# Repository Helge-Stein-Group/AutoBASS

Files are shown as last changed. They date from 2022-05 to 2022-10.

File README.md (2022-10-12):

# :battery: + :robot: + :factory: = AutoBASS 
AutoBASS deploys Automated Battery Assembly System. The motivation of this project is to meet the need of scaling-up and accuate assembly of in-house i.e. non-commercially acquired cells in battery reaserach, therefore enables the data-driven studies on optimization of active materials, electrolyte formulations, processing and manufacturing in a reproducible manner for the investigation of new chemistries.

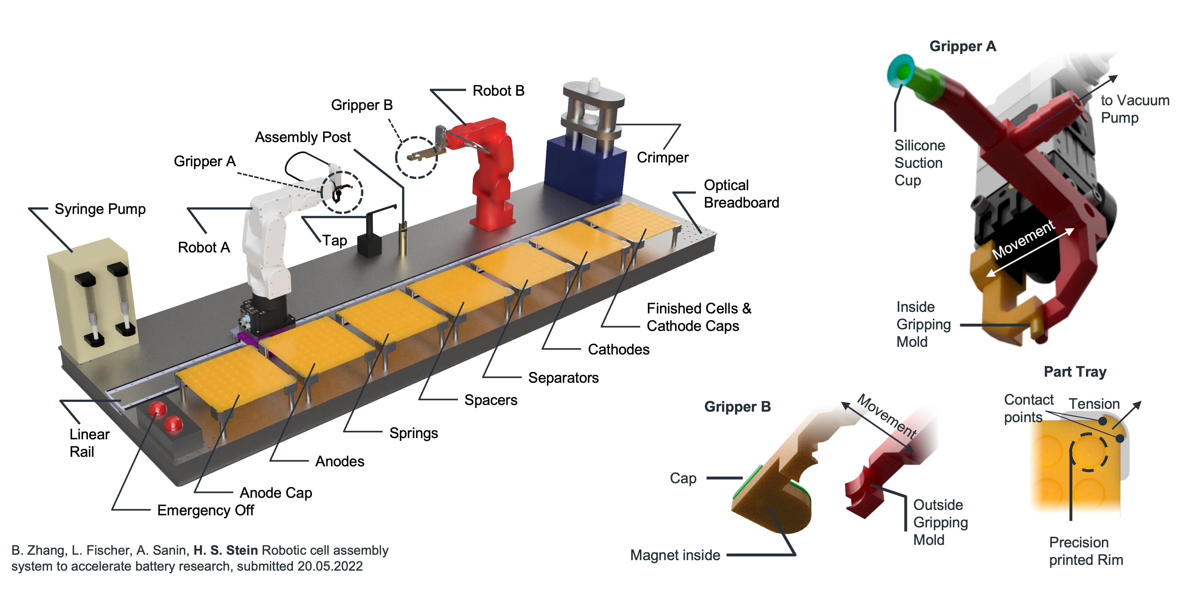
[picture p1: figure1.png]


## What are you here for?

I'm here for:
### Data
Please go to the data folder of this repo. There you will find four zip files which you need to download and unzip:
1. cell_data_published.pck 2.zip.001
2. cell_data_published.pck 2.zip.002
3. cell_data_published.pck 2.zip.003
4. cell_data_published.pck 2.zip.004

The problem is that github only allows binary files of 25 mb size so unzip them somewhere and then you'll get a pickle file that you can read in in python via:

```python
import pickle
data = pickle.load(open(r'/path/to/the/file/cell_data_published.pck','rb'))
```

We did this using python 3.7 so make sure you're not using an outdated version.
Then the data variable will contain all data for all cells (failed or not) as a list of dictionaries.
For each cell we record: 
#### **raw data**
Keys: I, V, t, index, Discharge_Capacity<br/>
Essentially what the arbin spits out. Index is the cycle index. The Discharge_Capacity is this strange Arbin thing which we keep in
#### **semi processed data**
Keys: ocv_assembly, channel, start_time, closing_time, dayli_id, Vsm<br/>
We write down that potential of the first few seconds, which channel was used, when the cycling started, when the cell was closed, some id to track cells internally and a smoothed voltage profile
#### **Cell images**
Keys: anode_image, separator_image, cathode_image<br/>
Relatively self explanatory by name. If there is no image the camera faulted
#### **Derived data**
Keys: dQdV, Q <br/>
This is data we calculate

#### Example Data access:

Ok let's say we want to see the voltage profile of cell 42 the we do this:

```python
import pickle
data = pickle.load(open(r'/path/to/the/file/cell_data_published.pck','rb'))

plt.plot(data[42]['t'],data[42]['V'])
plt.xlabel('Time [s]')
plt.ylabel('Voltage [V]')
```

If you look at the dQ/dV data make sure to scale the plots right as there is still considerable noide in the data. We recooment to plot vs. the smoother Voltage profile which is in the Vsm key.

### Building my own
Have a look at the stl files in the mechanical parts folder.
You will need
1. A Crimper
2. 2x Mecademic Meca 500 r.3
3. 2x Meca compatible Schunk Grippers
4. Jenny Science Linax Linear rail
5. Optical table
6. A 3D printer
7. Possibly our help
8. A very large glovebox

Please reach out to us if you are planning to set one up in your lab as there are some practical issues to be considered like the Athmosphere of your glovebox. We recommend to not use Argon as robots can fail very fast due to overheating issues. The GUI Bojing wrote makes a lot of the aligning tasks a lot easier (you will need this too).

Consider getting a glovebox with forced laminar flow as otherwise there can be issues of trapped gases.

The crimper is typically quite heavy and does not need to be fixed additonally. Overall you "just" need to assemble all parts and teach the robot the positions. We taught the robot ALL prositions manually.

### Lurking
Have a look at the data or code then? Or read the paper which ist published at [JOURNAL]

## Motivation
In battery research, manual coin cell assembly is still the most widely used methode to manufacture the in-house cells for testing, but the precise placement of electrodes and timing of electrolyte injection are challenging for researchers who manually perform the assembly inside of a glovebox. The small variations in manufacturing processe strongly impacts the intrinsic variability the overall system performance such as capacity, resistance and degradation rate between cells, which is a crucial issue that needs to be addressed while performing the data-driven stuides, therefore, we see it35 a pressing need to automate the assembly process, enabling the manufacturing of larger numbers of cells in a reproducible manner for the investigation of new chemistries. We, therefore, build the automatic battery assembly system (AutoBASS) which is capable of assmeblying up to 64 coin cells in a batch, the main parts of AutoBASS consist of two 6-axis robotic arms (Mecademic meca500 rev.2), a linear rail (Jenny Science Linax LXS 1800), and a programmable syring pump, providing a accuracy of placement in 0.2mm and that of electrolyte despersing in 1nL. The assembly procedure is accroding to the standard assembly procedure of Coin Cell 2032 recommonded by BIG-MAP. A graphic user interface is specificly designed for proper operating of the system. Image of electrodes upon placement and real-time record of events during operating of the system were created to help keep track of the variablilty of the cells.

## Design
In principle, the assembly procedure in AutoBASS consists of three major steps i.e. placing of conponents, injection of electrolyte, and crimping of cell, which are executed by sequentially calling actions of corresponding devices. The major devieces are two 6-axis robotic arms (assemblying and transporting robots) and one linear rail. In step placing, the assemblying robot mounted on the linear rail need to work coorperatively due to the limitaion of the robot's working area i.e. the relocation of assemblying robot in x-axis will be acomplished by the linear rail, whereas changes of tool's position in y-axis will be conducted by the assembly robot. Positions of each pits on the tray are identified with numbers from 1 to 64, associated with the components' names and specific positions and saved in a json file, which will be recalled while implementing the pick-up sequence. The injection of electrolyte is executed by calling the action of the syring pump (Halmiton Microlab 600) and a step-motor-controlled rotating electrolyte tap connect to it. Images will be taken upon the placement of anode and separator using a HD camera atached to the assemblying robot.In the crimping step, the transporting robot is used first transfering the closed cell intto the pressure adjustable electric crimper (MTI MSK-160E) which will be then triggered by a mictrocontroller relay connected to it. The sealed cell will be then grapped from the crimping die and placed agian on the assembly post through a magnetic mold mounted on the transporting robot. The finished cell will be eventally transfered to the vacant position of the tray holding cathode cups.

## Structure
For each individual devices, corresponding script is implemented responsible for controlling i.e. performing the required actions at specific time for example Robots.py is responsible for all actions which will be implemented by the assemblying and transfering robots. The complete automatic assembly procedure is organized by Assembly.py. Robot_test_UI.py can be directly launched and is responsible for calibration of each positions associated with the accuracy of placing components. And if you need an easy approach to make cells, launching Autobass.py is highly recommened.

## Enviroment setup
AutoBASS is very easy-to-read and user-friendly,  besides hardware drivers you just need a working python 3.7 installation and the drivers for the corresponding hardware as well. If you are using mecademic robots you need to install their (awesome!) python driver too.

## Launch script
AutoBaSS.py script can automatically guide you through the procedure from scratch:
    Launch 'AutoBass.py'
    Click "Assembly Coin Cell"
    Click "Initialize system" and wait for the progress bar to finish
    Type in the position of cell you want to start and to finish in numbers (No.1 refers to the cell on the up-left corner, No.64 refers to the one on the down-right corner)
    Click "Start Assembly" and the procedure will start

## Acknowledgements

This project has received funding from the European Union’s [Horizon 2020 research and innovation programme](https://ec.europa.eu/programmes/horizon2020/en) under grant agreement [No 957189](https://cordis.europa.eu/project/id/957189).

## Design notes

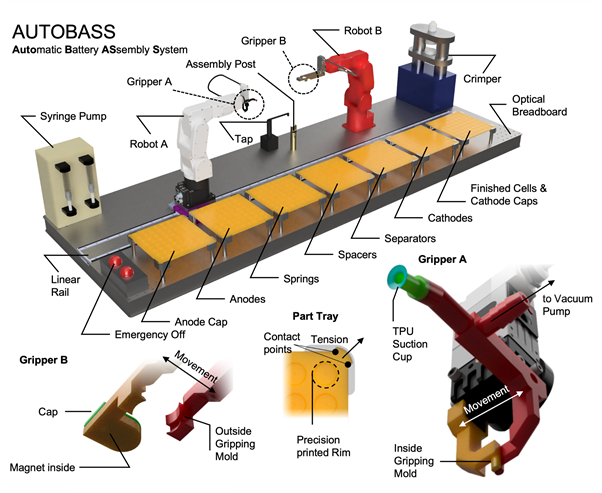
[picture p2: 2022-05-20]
AutoBASS.png

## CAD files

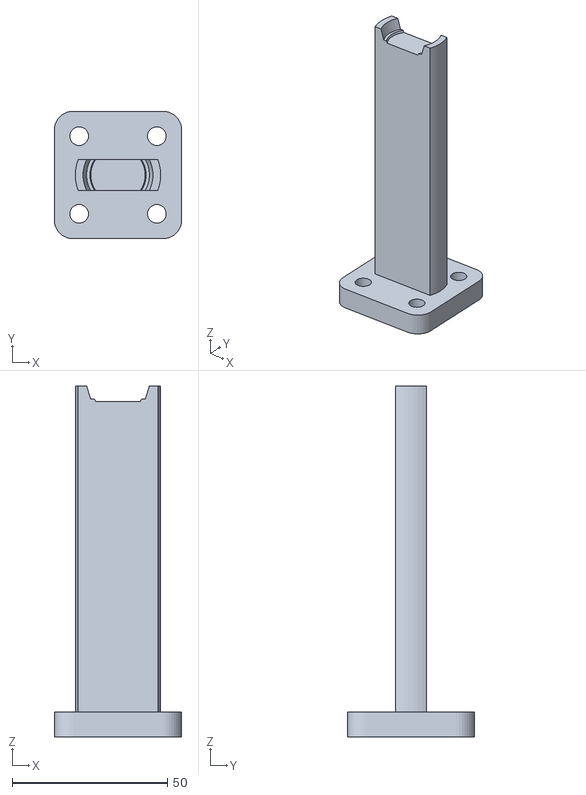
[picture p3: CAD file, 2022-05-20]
Mechanical Parts/Assembly Post/Assembly Post.stl
41.0 x 41.0 x 113.0

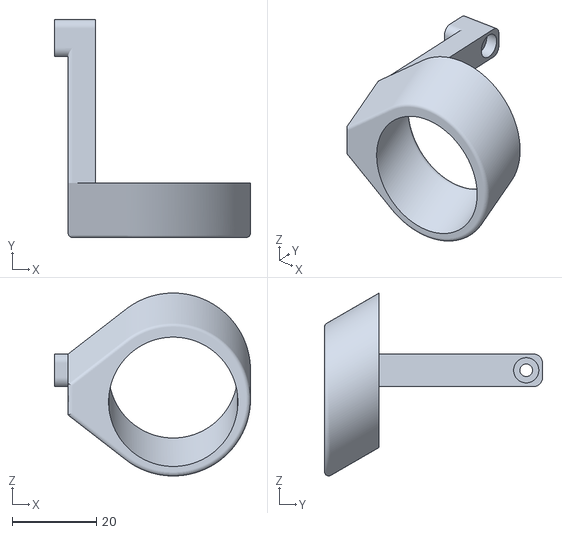
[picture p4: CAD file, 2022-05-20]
Mechanical Parts/Camera Holder/Camera Holder.stl
46.6 x 51.9 x 43.5

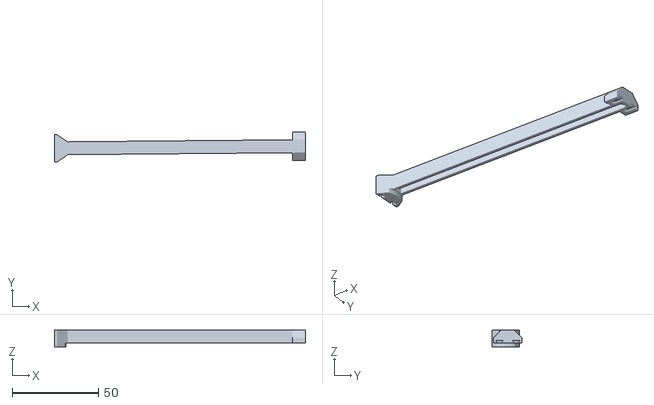
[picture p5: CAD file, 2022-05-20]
Mechanical Parts/Electrolyte Tap/Arm_Part1.stl
145.4 x 17.4 x 9.75

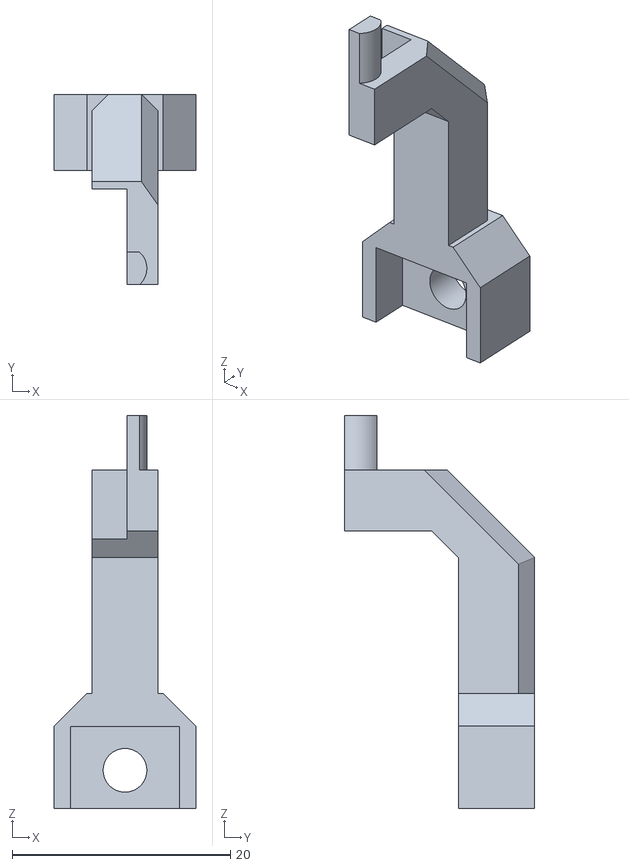
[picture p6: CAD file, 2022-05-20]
Mechanical Parts/Robots/Robot A/RightFinger.stl
13.0 x 17.4 x 36.0

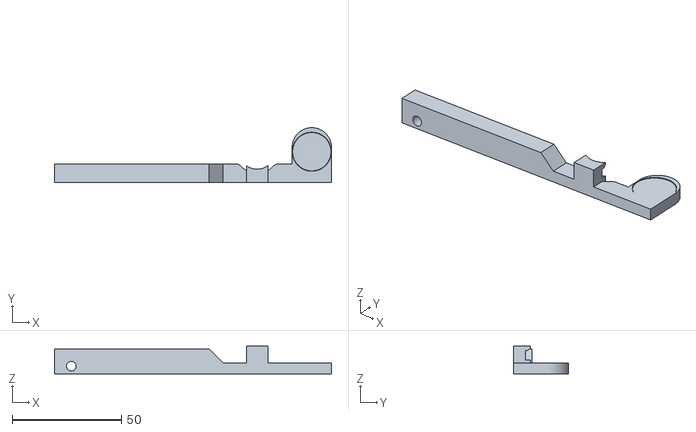
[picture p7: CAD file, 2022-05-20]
Mechanical Parts/Robots/Robot B/LeftGripper.stl
126.5 x 25.0 x 12.8

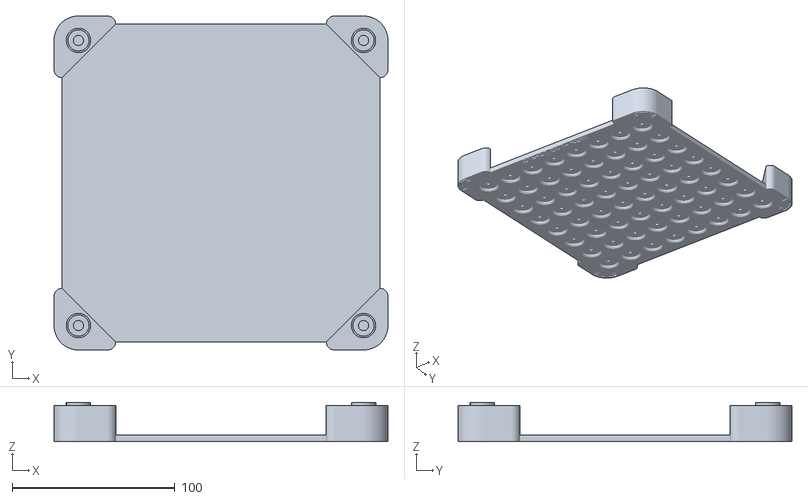
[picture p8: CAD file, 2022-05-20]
Mechanical Parts/Tray/All.stl
205.0 x 205.0 x 24.0

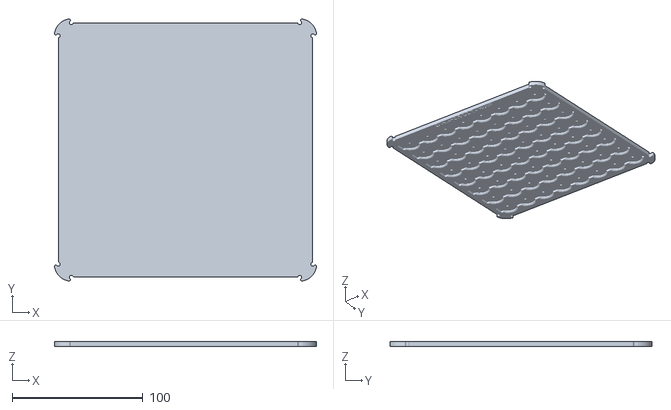
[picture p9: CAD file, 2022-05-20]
Mechanical Parts/Tray/MainBody/AnodeCase.stl
200.8 x 200.8 x 4.00

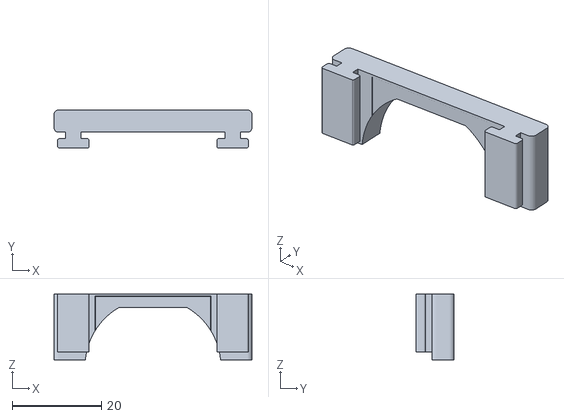
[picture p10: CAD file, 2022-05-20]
Mechanical Parts/Camera Holder/Shaft.stl
44.5 x 8.56 x 14.8

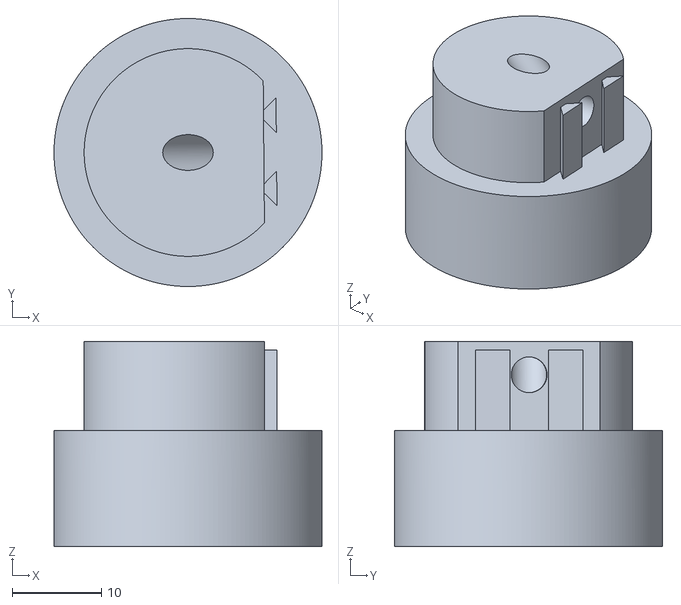
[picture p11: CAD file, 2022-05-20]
Mechanical Parts/Electrolyte Tap/Head.stl
30.0 x 30.0 x 23.0

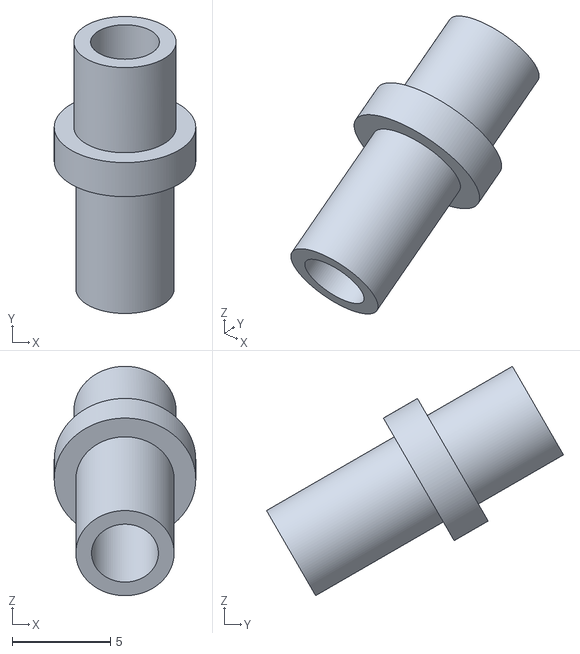
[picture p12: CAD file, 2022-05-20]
Mechanical Parts/Robots/Robot A/SuctionAdapter.stl
7.20 x 15.1 x 11.7

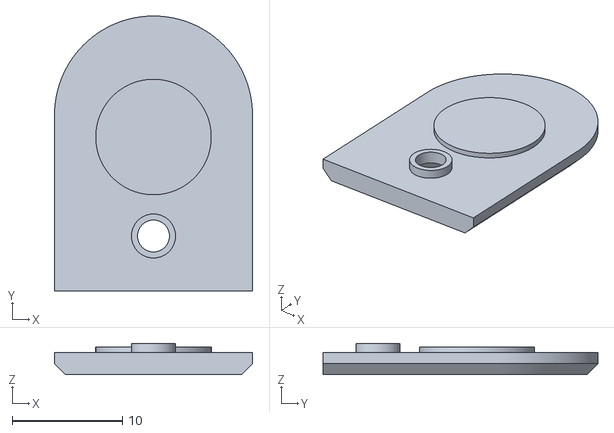
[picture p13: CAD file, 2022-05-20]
Mechanical Parts/Robots/Robot B/Lid.stl
18.0 x 25.0 x 2.85

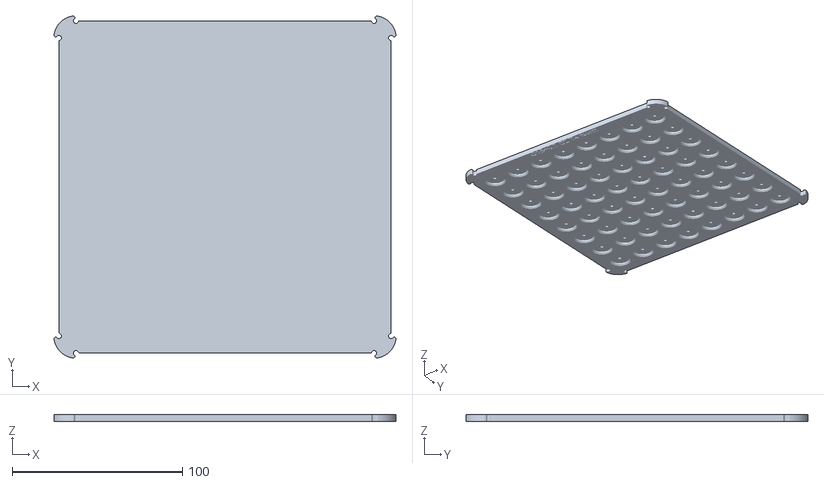
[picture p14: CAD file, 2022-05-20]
Mechanical Parts/Tray/MainBody/Anode.stl
200.8 x 200.8 x 4.00

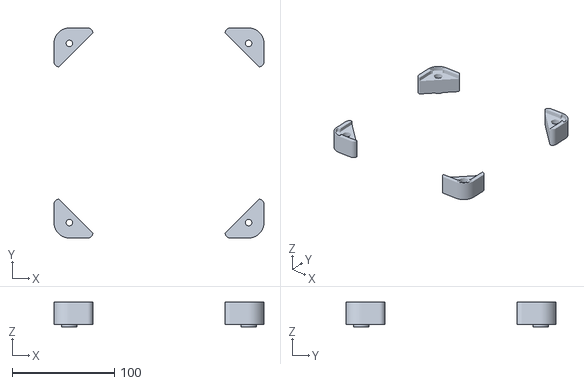
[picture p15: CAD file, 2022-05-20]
Mechanical Parts/Tray/TrayHolder.stl
205.0 x 205.0 x 24.0

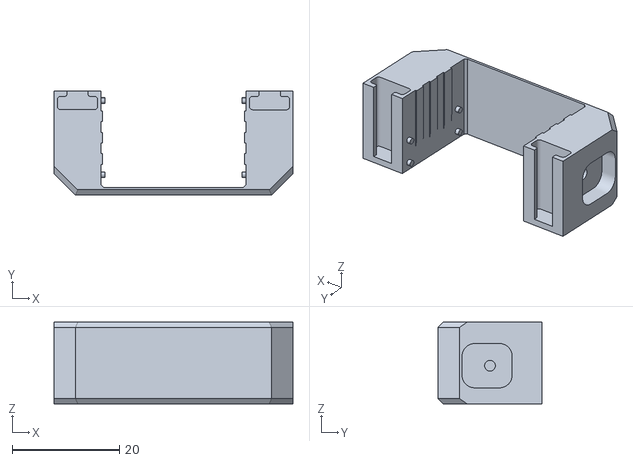
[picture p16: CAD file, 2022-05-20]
Mechanical Parts/Camera Holder/Holder Base.stl
44.5 x 19.4 x 15.2

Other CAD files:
Mechanical Parts/Electrolyte Tap/Motor_Case_Part1.stl
Mechanical Parts/Robots/Robot A/LeftFinger.stl
Mechanical Parts/Robots/Robot B/RightGripper.stl
Mechanical Parts/Tray/MainBody/CathodeCase.stl
Mechanical Parts/Electrolyte Tap/Arm_Part2.stl
Mechanical Parts/Electrolyte Tap/Motor_Case_Part2.stl
Mechanical Parts/Electrolyte Tap/Shaft.stl
Mechanical Parts/Tray/MainBody/Cathode.stl
Mechanical Parts/Tray/MainBody/Separator.stl
Mechanical Parts/Tray/MainBody/Spacer.stl
Mechanical Parts/Tray/MainBody/Washer.stl
Mechanical Parts/Tray/Optical pole adapter.stl

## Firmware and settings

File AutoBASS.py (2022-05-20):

from tkinter import *
from tkinter import font
from tkinter import messagebox
from tkinter import ttk
import os
import time
import threading
import Assembly as asb
import Robot_test_UI as testrob
from Position_generator import ResetParameter

PATH = os.path.dirname(__file__)
 
class AutobassGUI(ResetParameter):
    def __init__(self):
        ResetParameter.__init__(self)
        self.workflow = asb.Assembly()
        self.test_rubi = testrob.TestAssemblyRobot()
        self.test_pangpang = testrob.TestTransportRobot()
        self.init_window = Tk()

        # Specify font of labels and button's text
        global ft_label, ft_button
        ft_label = font.Font(family='Arial', size=12)
        ft_button = font.Font(size=15)

        # Specify variable for gui status
        self.gui_state = None

    def set_init_window(self):
        os.chdir(f"{PATH}\images")
        # Set the title, icon, size of the initial window
        self.init_window.title("AutoBASS GUI")
        self.init_window.iconbitmap("Robotarm.ico")
        self.init_window.geometry("820x450")

        for widget in self.init_window.winfo_children():
            widget.destroy()

        init_frame = LabelFrame(self.init_window, padx=50, pady=20, borderwidth=5)
        init_frame.grid(row=0, column=0, padx=20, pady=25)

        init_label_1 = Label(init_frame, text="Select from following operations:", pady=5, font=('Arial', 14))
        init_label_1.grid(row=0, column=0, columnspan=3, pady=30)

        init_btn_1 = Button(init_frame, text="Assembly Coin Cell", font=ft_button,\
                    padx=10, pady=40, border=5, borderwidth=4, command=self.set_assembly_window)
        init_btn_2 = Button(init_frame, text="Calibrate Robots", font=ft_button,\
                    padx=20, pady=38, border=5, borderwidth=4, command=self.set_calibration_window)
        init_btn_3 = Button(init_frame, text="Shut Down System", font=ft_button,\
                        padx=10, pady=38, border=5, borderwidth=4, command=self.shutdown_system)
        exit_btn = Button(self.init_window, text="Exit", font=ft_button,\
                    padx=52, borderwidth=4, command=self.init_window.destroy)

        init_btn_1.grid(row=1, column=0, padx=10)
        init_btn_2.grid(row=1, column=1, padx=10)
        init_btn_3.grid(row=1, column=2, padx=10)
        exit_btn.grid(row=2, column=0)

        self.init_window.mainloop()

    def set_assembly_window(self):
        
        self.init_window.title("Cell Assembly Interface")
        self.init_window.geometry("425x600")

        for widget in self.init_window.winfo_children():
            widget.destroy()

        # Create status bar
        self.assembly_status = StringVar()
        status_label = Label(self.init_window, textvariable=self.assembly_status, font=('Arial', 13), height=2, bd=2, relief=SUNKEN)
        status_label.grid(row=0, column=0, sticky=W+E)
        self.assembly_status.set("Initiate System and Give the Start and End number")

        # Creat input frame
        assembly_frame = LabelFrame(self.init_window, padx=20, pady=10)
        assembly_frame.grid(row=1, column=0, padx=20, pady=10)

        # Creat input frame
        input_frame = LabelFrame(assembly_frame, padx=50, pady=20)
        input_frame.grid(row=0, column=0, columnspan=2, pady=10)

        # Creat labels
        start_number_label = Label(input_frame, text="First Cell to assemble:", pady=15, font=ft_label)
        end_number_label = Label(input_frame, text="Last Cell to assemble:", pady=15, font=ft_label)

        start_number_label.grid(row=0, column=0)
        end_number_label.grid(row=1, column=0)
        
        # Create input fields
        global start_number_input, end_number_input
        start_number_input = Entry(input_frame, width=10, borderwidth=5)
        end_number_input = Entry(input_frame, width=10, borderwidth=5)

        start_number_input.grid(row=0, column=1)
        end_number_input.grid(row=1, column=1)

        # Create assembly button
        global assembly_btn, initiate_btn, config_btn, abort_btn, prime_pump_btn
        config_btn = Button(assembly_frame, text="Config System",  padx=3, pady=24, borderwidth=4, font=ft_button, command=self.start_config_gui)
        initiate_btn = Button(assembly_frame, text="Initiate System", padx=3, borderwidth=4, font=ft_button, command=self.init_assembly_system)
        prime_pump_btn = Button(assembly_frame, text="Prime Pump", padx=15, borderwidth=4, font=ft_button, command=self.workflow.dispensor.prime_pump)
        assembly_btn = Button(assembly_frame, text="Start Assembly", padx=85, pady=25, borderwidth=4, font=ft_button, command=self.verify_assembly_input)
        back_btn = Button(self.init_window, text="Back", borderwidth=4, padx=34, font=ft_button, command=self.set_init_window)
        exit_btn = Button(self.init_window, text="Exit", borderwidth=4, padx=40, font=ft_button, command=self.init_window.destroy)
        
        config_btn.grid(row=2, column=0, rowspan=2, padx=5)
        initiate_btn.grid(row=2, column=1, padx=5)
        prime_pump_btn.grid(row=3, column=1, padx=5)
        assembly_btn.grid(row=4, column=0, columnspan=2, pady=10)
        back_btn.grid(row=3, column=0, pady=5)
        exit_btn.grid(row=4, column=0, pady=5)

        if self.workflow._sys_is_on != True:
            start_number_input['state'] = 'disabled'
            end_number_input['state'] = 'disabled'
            assembly_btn['state'] = 'disabled'
            prime_pump_btn['state'] = 'disabled'

    def set_calibration_window(self):
        # Start a new window
        #self.init_window = Toplevel()
        self.init_window.title("Robot Calibration Interface")
        #self.init_window.iconbitmap("Robotarm.ico")
        self.init_window.geometry("570x450")

        for widget in self.init_window.winfo_children():
            widget.destroy()

        # Creat input frame
        cali_frame = LabelFrame(self.init_window, padx=50, pady=50, bd=5)
        cali_frame.grid(row=0, column=0, padx=20, pady=25)

        # Creat labels
        cali_label_1 = Label(cali_frame, text="Select The Robot to test:", pady=5, font=ft_label)
        cali_label_1.grid(row=0, column=0, columnspan=3, pady=10)

        # Create choices of testing robots
        cali_btn_1 = Button(cali_frame, text="Assembly Robot", font=ft_button,\
                        padx=10, pady=40, border=5, borderwidth=4, command=self.test_assembly)
        cali_btn_2 = Button(cali_frame, text="Transport Robot", font=ft_button, padx=15,\
                        pady=40, border=5, borderwidth=4, command=self.test_transport)
        exit_btn = Button(self.init_window, text="Exit", font=ft_button,\
                    padx=40, borderwidth=4, command=self.init_window.destroy)
        back_btn = Button(self.init_window, text="Back", font=ft_button, padx=34,\
                borderwidth=4, command=self.set_init_window)

        cali_btn_1.grid(row=1, column=0, padx=10)
        cali_btn_2.grid(row=1, column=1, padx=10)
        back_btn.grid(row=2, column=0, pady=5)
        exit_btn.grid(row=3, column=0, padx=10, pady=5)
        
    def test_assembly(self):
        self.gui_state = 'TestAssembly'
        self.init_window.state(newstate='iconic')
        self.test_rubi.set_test_assembly()

    def test_transport(self):
        self.gui_state = 'TestTransport'
        self.init_window.state(newstate='iconic')
        self.test_pangpang.init_trans_test_gui()

    def verify_assembly_input(self):
        try:
            self.start_number = int(start_number_input.get())
            self.end_number = int(end_number_input.get())
        except ValueError:
            messagebox.showerror("Input Error!", "Please put in Numbers!")
            start_number_input.delete(0, END)
            end_number_input.delete(0, END)
            self.assembly_status.set("Please put in numbers")
        else:
            if self.start_number <= 0 or self.start_number > 64 or self.end_number <= 0 or self.end_number > 64:
                messagebox.showerror("Input Error", "Input Numbers are out of range (1-64)!")
                start_number_input.delete(0, END)
                end_number_input.delete(0, END)
                self.assembly_status.set("Input Numbers are out of range!")
            elif self.end_number < self.start_number:
                messagebox.showerror("Input Error", "Starting number must be higher than ending number!")
                start_number_input.delete(0, END)
                end_number_input.delete(0, END)
                self.assembly_status.set("Starting number must be higher than ending number!")
            elif self.workflow._sys_is_on is True:
                assembly_btn["state"] = 'disabled'
                #self.assembly_rob_thread(self.start_assembly_rob)
                self.assembly_gui()
            else:
                messagebox.showerror("Error!", "System needs to be initiated first!")
    
    def assembly_gui(self):
        start_number_input['state'] = 'disabled'
        end_number_input['state'] = 'disabled'
        self.init_window.state(newstate='iconic')
        
        global asebl_prog_window, prog_text
        asebl_prog_window = Toplevel()
        asebl_prog_window.title("Assembly Progress")
        asebl_prog_window.geometry('320x220')
        prog_text = StringVar()
        prog_label = Label(asebl_prog_window, textvariable=prog_text, font=ft_label)
        progbar = ttk.Progressbar(asebl_prog_window, length=200, mode='determinate', orient=HORIZONTAL)

        global abort_btn, pause_btn
        abort_btn = Button(asebl_prog_window, text="Abort", padx=35, pady=25, borderwidth=4, font=ft_button, command=self.abort)
        pause_btn = Button(asebl_prog_window, text="Pause", padx=32, pady=25, borderwidth=4, font=ft_button, command=self.pause)
        
        progbar.grid(row=1, column=0, columnspan=2, pady=10)
        prog_label.grid(row=2, column=0, columnspan=2, pady=10)
        pause_btn.grid(row=3, column=0, padx=5, pady=10)
        abort_btn.grid(row=3, column=1, padx=5, pady=10)

        global cell_nr
        cell_nr = None
        self.workflow._stop.clear()
        self.asbl_thread = threading.Thread(target=self.start_assembly_rob)
        self.asbl_thread.setDaemon(True)
        self.asbl_thread.start()
        time.sleep(0.1)
        while self.asbl_thread.is_alive():
            progbar['value'] = self.workflow._progress['status']
            if not self.workflow._pause.is_set():
                prog_text.set(f"Assembly Paused! Cell: {cell_nr} ({self.workflow._progress['status']}%)")
            if self.workflow._stop.isSet():
                prog_text.set(f"Aborting Cell {cell_nr}...")
                asebl_prog_window.update()
                start_number_input['state'] = 'normal'
                end_number_input['state'] = 'normal'
                assembly_btn['state'] = 'normal'
                time.sleep(3)
                asebl_prog_window.destroy()
                self.init_window.state(newstate='normal')
                break
            if self.workflow._pause.is_set() and not self.workflow._stop.isSet():
                prog_text.set(f"Assembly Cell {cell_nr} in progress: ({self.workflow._progress['status']}%)")
            asebl_prog_window.update()
        else:
            progbar['value'] = 100
            prog_text.set(f"Cell {cell_nr} completed: 100%)")
            self.assembly_status.set(f"Assembly {cell_nr} completed!")
            asebl_prog_window.update()
            time.sleep(2)
            asebl_prog_window.destroy()
            start_number_input['state'] = 'normal'
            end_number_input['state'] = 'normal'
            assembly_btn['state'] = 'normal'
            self.init_window.state(newstate='normal')
    
    def init_assembly_system(self):
        self.gui_state = 'Assembly'
        os.chdir(f"{PATH}\images")
        if self.workflow._sys_is_on != True:
            initiate_btn['state'] = 'disabled'
            prog_window = Toplevel()
            prog_window.title("Assembly Robot initializing")
            prog_window.iconbitmap("Robotarm.ico")
            prog_window.geometry('280x150')
            prog_text = StringVar()
            prog_label = Label(prog_window, textvariable=prog_text, font=ft_label, pady=10, anchor=CENTER)
            prog = ttk.Progressbar(prog_window, length=250, mode='determinate', orient=HORIZONTAL)
            prog_label.grid(row=2, column=0, columnspan=2)
            prog.grid(row=1, column=0)
            count = 0
            init_thread = threading.Thread(target=self.workflow.initiate_all)
            init_thread.setDaemon(True)
            init_thread.start()
            prog.start(500)
            while True:
                prog['value'] = self.workflow._progress['status']
                prog_text.set(f"Initiating System, Please Wait ({prog['value']}%)")
                prog_window.update()
                if not init_thread.is_alive():
                    prog.stop()
                    prog['value'] = 100
                    prog_text.set(f"Initiating Complete Finishing.......({prog['value']}%)")
                    prog_window.update()
                    time.sleep(2)
                    prog_window.destroy()
                    start_number_input['state'] = 'normal'
                    end_number_input['state'] = 'normal'
                    initiate_btn['state'] = 'normal'
                    assembly_btn['state'] = 'normal'
                    prime_pump_btn['state'] = 'normal'
                    self.assembly_status.set("Initiatiing completed, click [Start Assembly] to start")
                    break
                if count >= 100:
                    raise TimeoutError
                time.sleep(1)
                count += 1
            prog_window.mainloop()
        else:
            messagebox.showinfo("Attention!", "System is already initialized!")

    def start_assembly_rob(self):
        global cell_nr
        self.workflow.apply_set_up()
        for cell_nr in range(self.start_number, self.end_number+1):
            self.assembly_status.set(f"Assembly Cell {cell_nr}")
            self.workflow.one_cell(cell_nr)
            if self.workflow._stop.isSet():
                break
            time.sleep(2)

    def check_assembly_exe(self):
        if not self.assembly_rob_exe.is_alive():
            self.assembly_status.set(f"Cell {cell_nr} Complete: 100%")
        else:
            self.assembly_status.set(f"Assembly Cell {cell_nr}: {self.workflow._progress['status']}%")
            self.init_window.after(100, self.check_assembly_exe)

    def assembly_rob_thread(self, func):
        self.assembly_rob_exe = threading.Thread(target=func)
        self.assembly_rob_exe.setDaemon(True)
        self.assembly_rob_exe.start()
        self.check_assembly_exe()

    def pause(self):
        self.workflow.pause()
        pause_btn.config(text='Resume', padx=35, command=self.resume)

    def resume(self):
        self.workflow.resume()
        pause_btn.config(text='Pause', padx=42, command=self.pause)

    def abort(self):
        self.workflow.abort()

    def shutdown_system(self):
        shutdown_thread = threading.Thread(target=self.shutdown_system_rob)
        shutdown_thread.setDaemon(True)
        shutdown_thread.start()
            
    def shutdown_system_rob(self):
        if self.gui_state == 'Assembly':
            #self.workflow.power_off()
            try:
                self.workflow.power_off()
            except:
                print("Assembly Procedure is not online!")
            else:
                messagebox.showinfo("Information", "AuoBASS is offline!")
        elif self.gui_state == 'TestAssembly':
            try:
                self.test_rubi.end_assembly_test()
            except:
                print("Assembly Test is not online!")
            else:
                messagebox.showinfo("Information", "Assembly Robot is offline!")
        elif self.gui_state == 'TestTransport':
            try:
                self.test_pangpang.end_trans_test()
            except:
                print("Transport Test is not online!")
            else:
                messagebox.showinfo("Information", "Transport Robot is offline!")
        else:
            pass

if __name__ == "__main__":
    os.chdir(PATH)
    ao = AutobassGUI()
    ao.set_init_window()

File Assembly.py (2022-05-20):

import time
import json
import os
import threading
import numpy as np
import Crimper
import Dispensor
import notify as nf
import Robots
import Rail

# Get the folder path
PATH = os.path.dirname(__file__)

# Assembly constant
COMPONENTS = np.array(['anode case', 'anode spacer', 'anode', 'separator', 'cathode', 'cathode spacer', 'spring', 'cathode case'])


class Assembly():
    def __init__(self):
        self.my_rail = Rail.Rail()
        self.rubi = Robots.AssemblyRobot()
        self.pangpang = Robots.TransportRobot()
        self.dispensor = Dispensor.Dispensor()
        self.badass = Crimper.Crimper()
        self._sys_is_on = None
        self._stop = threading.Event()
        self._pause = threading.Event()
        self._pause.set()

    def load_parameter(self):
        os.chdir(f"{PATH}\data")
        with open('config.json') as json_file:
            parameter = json.load(json_file)
        self.parameter = parameter
        nf.log_print("Assembly config file loaded")
        # Format: {'Component Name': [Holer Position, Grab z value, Drop z value, [Pre-Drop Positoion], {'Component Nr.': [Pre-grab Position]}]}

    def apply_set_up(self):
        os.chdir(f"{PATH}\data")
        with open('config.json') as json_file:
            parameter = json.load(json_file)
        self.rubi.SetJointVel(parameter['J_VEL'])
        self.rubi.SetCartLinVel(parameter['L_VEL'])
        self.rubi.SetGripperVel(parameter['GRIP_VEL'])
        self.rubi.SetGripperForce(parameter['GRIP_F'])
        self.pangpang.SetJointVel(parameter['J_VEL'])
        self.pangpang.SetCartLinVel(parameter['L_VEL'])
        self.pangpang.SetGripperVel(parameter['GRIP_VEL'])
        self.pangpang.SetGripperForce(parameter['GRIP_F'])
        self.dispensor.config_volume()
        #self.my_rail.set_vel(parameter['AX_VEL'])

    def initiate_all(self):
        self._progress = dict(cell_nr=None, component=None, status=0)
        try:
            self.my_rail.connect_rail()
            self._progress.update(component='Rail', status=20)
            self.rubi.initiate_robot()
            self._progress.update(component='AssemblyRobot', status=40)
            self.pangpang.initiate_robot()
            self._progress.update(component='TransportRobot', status=60)
            self.dispensor.connect_dispensor()
            self._progress.update(component='Dispensor', status=80)
            self.badass.connect_crimper()
            self._progress.update(component='Crimper', status=100)
        except:
            self._sys_is_on = False
        else:
            self._sys_is_on = self.check_sys_sts()

    def one_cell(self, component_Nr:int):
        # Load config file
        self.load_parameter()
        time.sleep(0.1)
        #Perform the whole assembly procedure for just one time
        self._stop.clear()
        self._progress.update(cell_nr=component_Nr, component=None, status=0)

        for component in COMPONENTS:

            # Calculate the position for individual cell-Nr.
            grab_po = self.parameter[component]['grabPo'][str(component_Nr)]
            drop_po = self.parameter[component]['dropPo'][str(component_Nr)]
            holder_pos =  self.parameter[component]['railPo'] + (component_Nr-1)//8*23

            nf.log_print(f"Processing {component} of NO. {component_Nr}:", logfile='assembly')
            self._progress.update(component=component)
            
            # Rail move to the start position
            # Pause/abort flag
            self._pause.wait()
            if self._stop.isSet():
                self.home_all()
                return

            nf.log_print(f'Moving to tray [{component}]', logfile='assembly')
            self.my_rail.move(holder_pos)
            self._progress['status'] += 1

            # Grip COMPONENTS from the tray
            # Pause/abort flag
            self._pause.wait()
            if self._stop.isSet():
                self.home_all()
                return

            nf.log_print(f'Grabing {component}', logfile='assembly')
            self.rubi.grab_component(grab_po)
            self._progress['status'] += 1

            # Drive the rail to drop position
            # Pause/abort flag
            self._pause.wait()
            if self._stop.isSet():
                self.home_all()
                return

            nf.log_print(f'Transporting {component} to post', logfile='assembly')
            self.my_rail.move(self.parameter['post'])
            self._progress['status'] += 1

            # Drop COMPONENTS on the post
            # Pause/abort flag
            self._pause.wait()
            if self._stop.isSet():
                self.home_all()
                return

            nf.log_print(f'Dropping {component} on post', logfile='assembly')
            self.rubi.drop_component(drop_po, component, component_Nr)
            self._progress['status'] += 1
            time.sleep(0.5)

            # Drop electrolyt onto the anode and separator
            # Pause/abort flag
            self._pause.wait()
            if self._stop.isSet():
                self.home_all()
                return

            self.dispensor.add_electrolyte(component)
            self._progress['status'] += 1

        # Rail move to nearby position to avoid collision
        # Pause/abort flag
        self._pause.wait()
        if self._stop.isSet():
            self.home_all()
            return

        nf.log_print("Assembly Robot moving away", logfile='assembly')
        self.my_rail.move(600)
        self._progress['status'] += 6

        # Align the components with TransportRobot
        # Pause/abort flag
        self._pause.wait()
        if self._stop.isSet():
            self.home_all()
            return

        nf.log_print("Aligning cell on post", logfile='assembly')
        self.pangpang.align_cell()
        self._progress['status'] += 6

        # Rail move to post again, ready to press
        # Pause/abort flag
        self._pause.wait()
        if self._stop.isSet():
            self.home_all()
            return

        nf.log_print("Assembly Robot moving back to post", logfile='assembly')
        self.my_rail.move(self.parameter['post'])
        self._progress['status'] += 6

        # Press the cell with gripper
        # Pause/abort flag
        self._pause.wait()
        if self._stop.isSet():
            self.home_all()
            return

        nf.log_print('Pressing COMPONENTS on the post', logfile='assembly')
        self.rubi.press_cell()
        self._progress['status'] += 6
        time.sleep(0.5)

        # Rail move to the home position to avoid collision
        # Pause/abort flag
        self._pause.wait()
        if self._stop.isSet():
            self.home_all()
            return

        nf.log_print('Assembly Robot moving Home, ready for crimping', logfile='assembly')
        self.my_rail.move(600)
        self._progress['status'] += 6
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

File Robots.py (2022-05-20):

import os
import time
import json
import cv2
from Ardurino_relay import Ardurelay
from MecademicRobot import RobotController
import notify as nf

PATH = os.path.dirname(__file__)
# IP address of robots
ASSEMBLY_HOST = "192.168.31.231"
TRANSPORT_HOST = "192.168.31.232"

# Arduino port
ARDU_PORT = 'COM8'

# Camera port
CAM_PORT = 1

# Robot Constant
os.chdir(f"{PATH}\data")

# Get latest constant values from config file
with open('config.json') as json_file:
    CONSTANT = json.load(json_file)
TCP_SK = CONSTANT['TCP_SK']
TCP_GP = CONSTANT['TCP_GP']
TCP_CP = CONSTANT['TCP_CP']
TCP_CP_180 = CONSTANT['TCP_CP_180']

class AssemblyRobot(RobotController, Ardurelay):

    def __init__(self, address=ASSEMBLY_HOST, vacuum_port=ARDU_PORT):
        RobotController.__init__(self, address)
        Ardurelay.__init__(self, vacuum_port)
        self.address = address

    def initiate_robot(self):
        # Activate robot, home, reset joints, apply parameters
        nf.log_print('Initiating AssemblyRobot...')
        self.connect_relay()
        msg = self.connect()
        time.sleep(0.1)
        if msg is True:
            msg = self.ActivateRobot()
            time.sleep(0.1)
            if msg == 'Motors activated.':
                msg = self.home()
                time.sleep(0.1)
                if msg == 'Homing done.':
                    # Set robot's parameter
                    self.SetCartLinVel(CONSTANT['L_VEL'])
                    self.SetJointVel(CONSTANT['J_VEL'])
                    self.SetJointAcc(50)
                    self.SetGripperForce(CONSTANT['GRIP_F'])
                    self.SetGripperVel(CONSTANT['GRIP_VEL'])
                    self.MoveJoints(0,0,0,0,0,0)
                    time.sleep(0.01)
                    nf.log_print('AssemblyRobot initiated.')
                    self.cam = cv2.VideoCapture(CAM_PORT)
                    nf.log_print('Camera online.')
                else:
                    nf.log_print('AssemblyRobot already homed!')
            else:
                nf.log_print('AssemblyRobot already activated!')
        elif msg == 'Another user is already connected, closing connection':
            nf.log_print('AssemblyRobot already in connection!')
        else:
            nf.log_print('AssemblyRobot is not in connection. Check Power buttom')

    def snap_shot(self, filename=''):
    # Ultilize the Webcam to capture image during manufacturing
        self.cam.open(CAM_PORT)
        discard_count = 0
        while discard_count < 2:
            ret, frame = self.cam.read()
            if ret is True:
                discard_count += 1
            time.sleep(0.5)
        os.chdir(f"{PATH}\Alignments")
        time_stamp = time.strftime("%d_%m_%Y_%Hh_%Mm_%Ss", time.localtime())
        if filename:
            filename = f"{filename}_{time_stamp}.jpg"
        else:
            filename = f"{time_stamp}.jpg"
        cv2.imwrite(filename, frame)
        self.cam.release()
        cv2.imshow(f"Image{filename}", frame)
        cv2.waitKey(2000)
        cv2.destroyAllWindows()

    def grab_component(self, grab_po):
    # Grabing materials from trays
        nf.log_print(f"Gripping on {grab_po}...")

        # Grab the component
        time.sleep(0.01)

        # Determine which tool to use for grabing
        if abs(grab_po[0]) >= 160:
        # Switch the TCP, Reset the joints' position
            self.SetTRF(*TCP_GP)
            time.sleep(0.1)
            self.MoveJoints(*CONSTANT['HOME_GP_J'])

            # Move to the start position
            self.MovePose(grab_po[0], grab_po[1], 40, grab_po[3], grab_po[4], grab_po[5])
            self.GripperOpen()
            time.sleep(0.5)

            # Gripper goes down
            self.MoveLin(*grab_po)
            time.sleep(0.5)

            # Gripping parts, ready to transport
            self.GripperClose()
            time.sleep(1)
            self.MoveLin(grab_po[0], grab_po[1], 40, grab_po[3], grab_po[4], grab_po[5])
            self.MoveJoints(*CONSTANT['HOME_GP_J'])

        elif abs(grab_po[0]) < 160:
        # Switch the TCP, Reset the joints' position
            self.SetTRF(*TCP_SK)
            time.sleep(0.1)
            self.MoveJoints(*CONSTANT['HOME_SK_J'])
            
            # Robot move to the start position
            self.MovePose(grab_po[0], grab_po[1], 40, grab_po[3], grab_po[4], grab_po[5])
            # Open Gripper settle sucktion cup into position
            self.GripperOpen()
            time.sleep(0.5)

            self.MoveLin(*grab_po)

            # Pump switching on
            self.suction_on()

            # Gripping parts, ready to transport
            time.sleep(2)
            self.MoveLin(grab_po[0], grab_po[1], 40, grab_po[3], grab_po[4], grab_po[5])
            self.MoveJoints(*CONSTANT['HOME_SK_J'])
        return True

    def drop_component(self, drop_po, component:str, nr:int):
    # Drop the material onto the post
        nf.log_print(f"Dropping on {drop_po}...")

        # Robot move to the start position
        self.MovePose(drop_po[0], drop_po[1], 100, drop_po[3], drop_po[4], drop_po[5])
        time.sleep(0.5)

        # Gripper goes down, and drop the parts
        self.MoveLin(*drop_po)

        time.sleep(0.5)
        if component == 'spring':
            time.sleep(1)
            self.GripperOpen()
            time.sleep(2)
        elif component == 'cathode case':
            # Perform tilling movement
            self.SetCartAngVel(5)
            self.MoveLinRelWRF(0.5,0,0.5,0,0,0)
            self.MoveLinRelWRF(0,0,0,0,2,0)
            self.MoveLinRelWRF(0,0,-1.5,0,0,0)
            self.MoveLinRelWRF(0,0,0,0,-2,0)
            self.suction_off()
            # Wait for enough time to release the vacuum
            time.sleep(4)
            self.SetCartAngVel(45)
        elif component in ('anode', 'separator', 'cathode'):
            self.SetCartAngVel(90)
            self.suction_off()
            # Wait for enough time to release the vacuum
            time.sleep(6)
            self.MoveLinRelWRF(0,0,10,0,0,0)
            self.SetCartAngVel(45)
            # Taking a snap shot
            nf.log_print(f'Taking snap shot on {component}', logfile='assembly')
            self.MoveJoints(*CONSTANT['SNAP_SHOT_J'])
            self.snap_shot(f"{component}_No{nr}")
            nf.log_print(f'Snap shot taken', logfile='assembly')
        elif component in ('anode case', 'anode spacer', 'cathode spacer'):
            self.suction_off()
            # Wait for enough time to release the vacuum
            time.sleep(6)
            
        # Homing the robot
        self.MoveLinRelWRF(0,0,30,0,0,0)
        self.MovePose(drop_po[0], drop_po[1], drop_po[2]+60, drop_po[3], drop_po[4], drop_po[5])
        self.MoveJoints(*CONSTANT['HOME_POST_J'])
        self.MoveJoints(*CONSTANT['HOME_SK_J'])
        return True
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
